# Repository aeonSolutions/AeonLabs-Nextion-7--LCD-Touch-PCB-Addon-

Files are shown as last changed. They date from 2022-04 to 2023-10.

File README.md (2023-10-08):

[PCB-Prototyping-Catalogue](https://github.com/aeonSolutions/PCB-Prototyping-Catalogue)  >>  [Smart LCD Touch Displays](https://github.com/aeonSolutions/PCB-Prototyping-Catalogue/tree/main/Smart%20LCD%20Touch%20Displays)  >>  AeonLabs Nextion 7" LCD Touch PCB Addon

<br>

<p align="right">
    sponsored by <br>
    <a href="https://www.pcbway.com/setinvite.aspx?inviteid=572526">
       
    </a>
</p>

# AeonLabs Nextion 7" LCD Touch PCB Addon 
This repo contains the KiCad files for the  WIFI &amp; BLE addon for Nextion 7" LCD Touch. This PCB adds WiFi and BLE capabilities to stock Nextion 7" LCDs (http://www.nextion.tech). Features WIFI, Bluetooth a RGB LED and a Buzzer and is designed to be mounted on top of existing Nextion PCB board. Optionally:
- can be installed with a RFID RC522 module for contactless read / write capabilities.
- can be installed a barcode & QR code wireless module for handheld barcode & QR code scanners

*Don't forget to LIKE , SHARE and subscribe the free whatsApp group* and if you liked this PCB consider buying me a cup of coffee. Links below.




### Status
  Powers up. Waiting to be tested.

If you already tested this PCB send me a message. Thank you

## Revisions
- revision 3.1
  - added barcode & QR code 2.4G wireless module for handheld barcode & QR code scanners
  - minor bug corrections to the PCB
  
- revision 2.4
  - added wired power source conenction for 5V to 12V 1A power input for industrial applications. 

PCB fabrication of June 2022 (reviision 3.1) was sponsored by [PCBWay](www.pcbway.com)

First Firmware download of AeonLabs's USB to UART TTL Burner (https://www.youtube.com/watch?v=EkAStzBm8CE "First Firmware download of AeonLabs's USB to UART TTL Burner")

## Download options
Download this repository if you need the KiCad Files. or, download the Gerber files in the release section of this repository

## Liked it ? Get a Free PCB for yourself
Send me your Device or hardware and i will design a custom PCB for it. Free of charge. Contact-me on WhatsApp or email for more info. 

## Q&A WhatsApp Group
If you have any Questions or simply  like this kind of projects and want to stay updated with the latest research ideas and prototypes during the day and week, join the WhatsApp Group
[A.I. Things](https://chat.whatsapp.com/FkNC7u83kuy2QRA5sqjBVg)

## Fully assembled PCB
Alternatively, and if you do not want to build a PCB by yourself and like to buy one:

(https://www.tindie.com/stores/aeonlabs/)

The price starts at 30eur plus postage fees.
(I will also deliver the assembled PCB with all the components in place at a fair aditonal cost).

## Nextion LCDs
If you like this , but on another NEXTION LCD TOUCH, drop me a DM on whatsApp [here](https://chat.whatsapp.com/FkNC7u83kuy2QRA5sqjBVg) and i will do for free the KiCad design for you.

#### Be supportive of my dedication and work towards technology education and buy me a coffee. Link below.

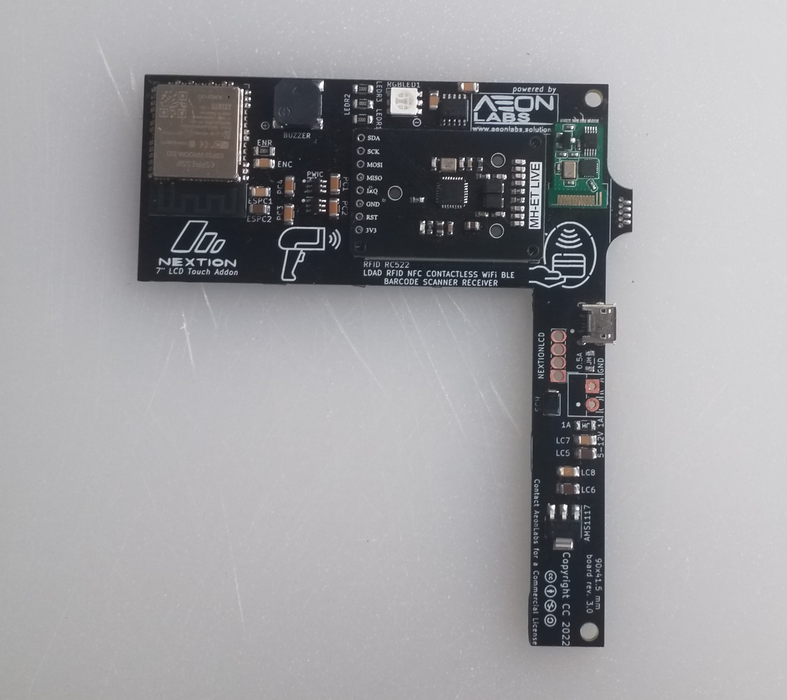
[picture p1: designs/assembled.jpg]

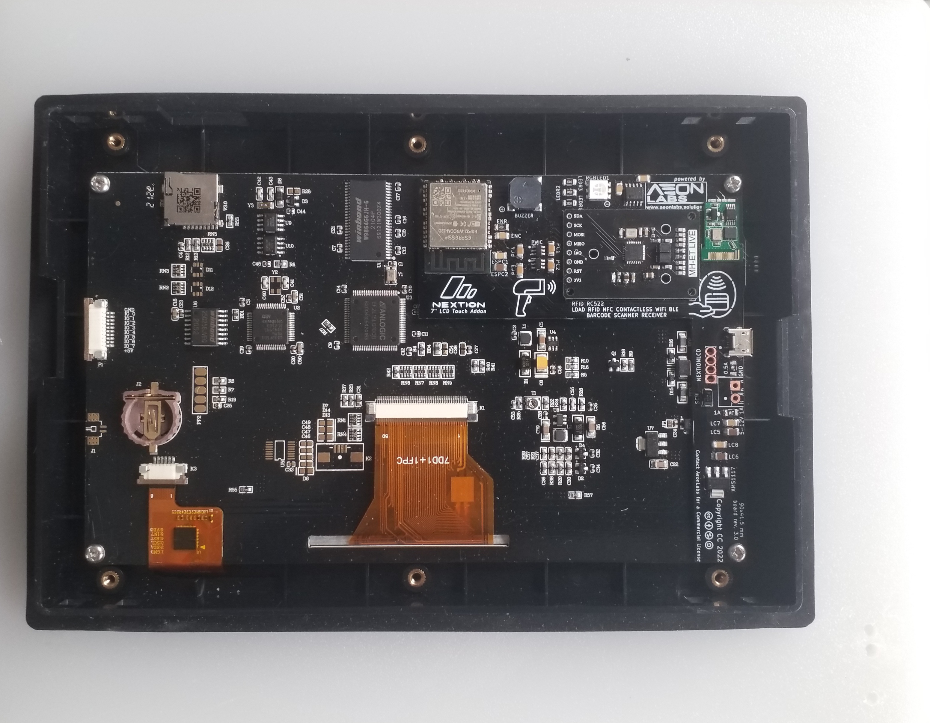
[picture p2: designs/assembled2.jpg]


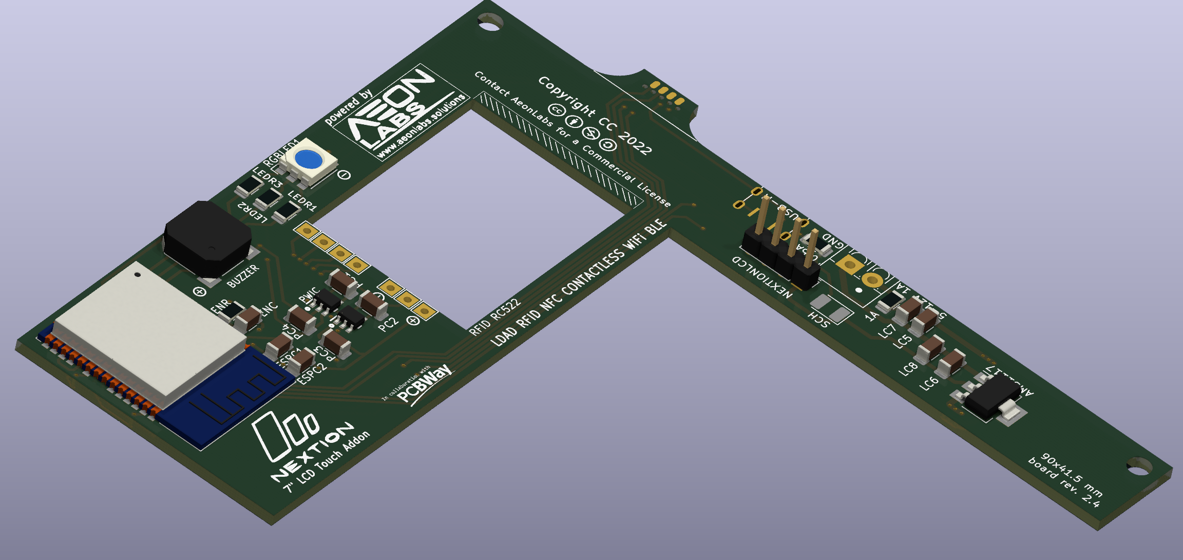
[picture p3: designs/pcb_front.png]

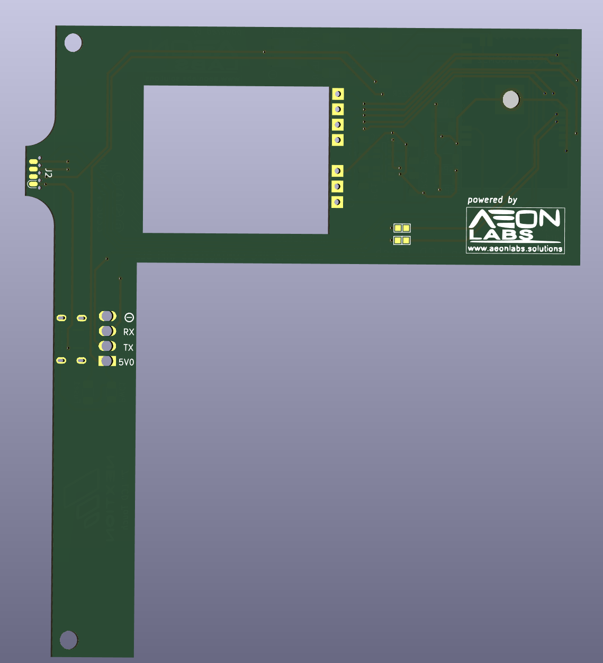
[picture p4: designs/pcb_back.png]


________________________________________________________________________________________________________________

## PCB Parts list
- DC2DC converter HX4002B x2 : https://s.click.aliexpress.com/e/_Ak7IPx
- Capacitor 100nF SMD 1206 : https://s.click.aliexpress.com/e/_AVdmzr
- Capacitor 2.2uF SMD 1206 : https://s.click.aliexpress.com/e/_AVdmzr
- Resistor SMD 1206 330R x3 : https://s.click.aliexpress.com/e/_A7OXrR
- ESP32 WROOM32 x1 : https://s.click.aliexpress.com/e/_AF7N6l
- Buzzer x1: https://s.click.aliexpress.com/e/_AF7N6l
- LED RGB x1: https://s.click.aliexpress.com/e/_AccXHT
- RFID RC522 x1 (optional) : https://s.click.aliexpress.com/e/_Am0LAH
- 

## Firmware Download 
one can use the PCB in the repository [AeonLabs-MCU-Burner-USB-to-UART-TTL](https://github.com/aeonSolutions/AeonLabs-MCU-Burner-USB-to-UART-TTL) to program the ESP32 WROOM32 MCU on this PCB.

<br />
<br />

______________________________________________________________________________________________________________________________

### PCB Conceptualization and Design
<p align="center">
 
[](https://saturnpcb.com) [](https://www.kicad.org) [](https://www.broadcom.com/appcad)

</p>

<br />
<br />

### PCB Fabrication
<p align="center">
 
[](https://www.allpcb.com/?Mb_InviteId=79483) [](https://www.pcbway.com/setinvite.aspx?inviteid=572526) [](https://be.eurocircuits.com)

</p>

<br />
<br />

## Author

You can get in touch with me on my LinkedIn Profile:

#### Miguel Tomas





You can also follow my GitHub Profile to stay updated about my latest projects: 

<br>

### Be supportive of my dedication and work towards technology education and buy me a cup of coffee
The PCB Desgin Files i provide here for anyone to use are free. If you like this Smart Device or use it, please consider buying me a cup of coffee, a slice of pizza or a book to help me study, eat and think new PCB design files.

<p align+"left">
<a href="https://www.buymeacoffee.com/migueltomas">
   
 </a>
<br>

</p>

<br />

### Make a donation on Paypal
Make a donation on paypal and get a TAX refund*.

(http://paypal.me/mtpsilva)

<br>

### Support all these open hardware projects and become a patreon  
Liked any of my PCB KiCad Designs? Help and Support my open work to all by becomming a LDAD Patreon.
In return I will give a free PCB design in KiCad to all patreon supporters. To learn more go to patreon.com. Link below.

(https://www.patreon.com/ldad)

<br />
<br />

______________________________________________________________________________________________________________________________
### License

Before proceeding to download any of AeonLabs software solutions for open-source development and/or PCB hardware electronics development make sure you are choosing the right license for your project. See [AeonLabs Solutions for Open Hardware & Source Development](https://github.com/aeonSolutions/PCB-Prototyping-Catalogue/wiki/AeonLabs-Solutions-for-Open-Hardware-&-Source-Development) for more information. 

______________________________________________________________________________________________________________________________

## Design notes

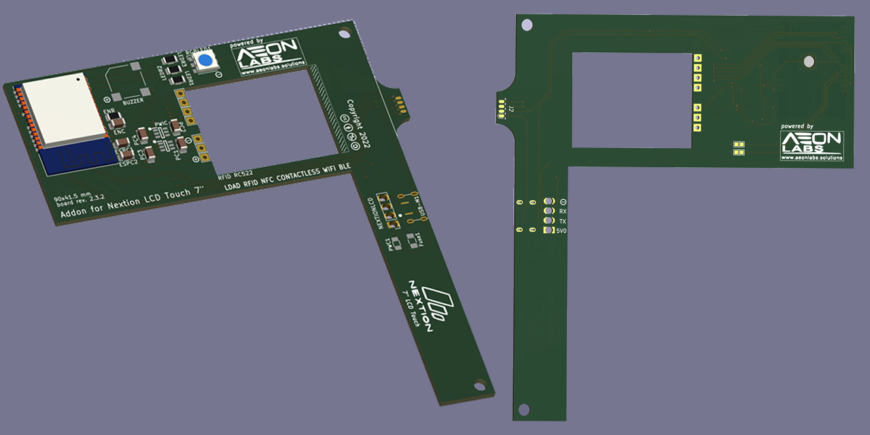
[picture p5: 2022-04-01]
designs/pcb.fw.png

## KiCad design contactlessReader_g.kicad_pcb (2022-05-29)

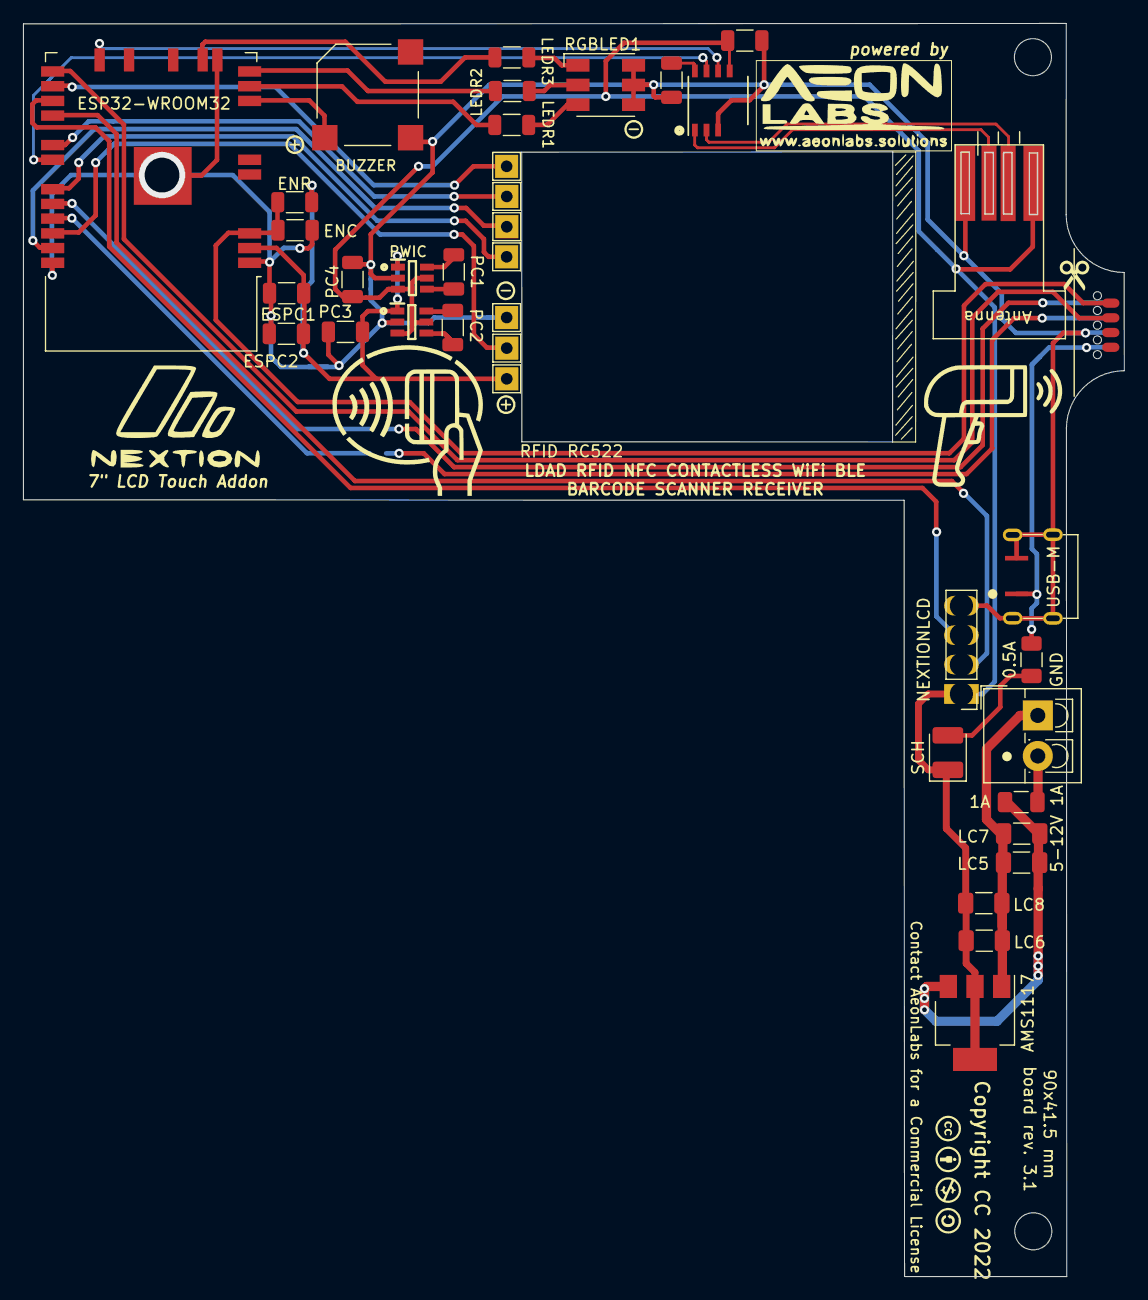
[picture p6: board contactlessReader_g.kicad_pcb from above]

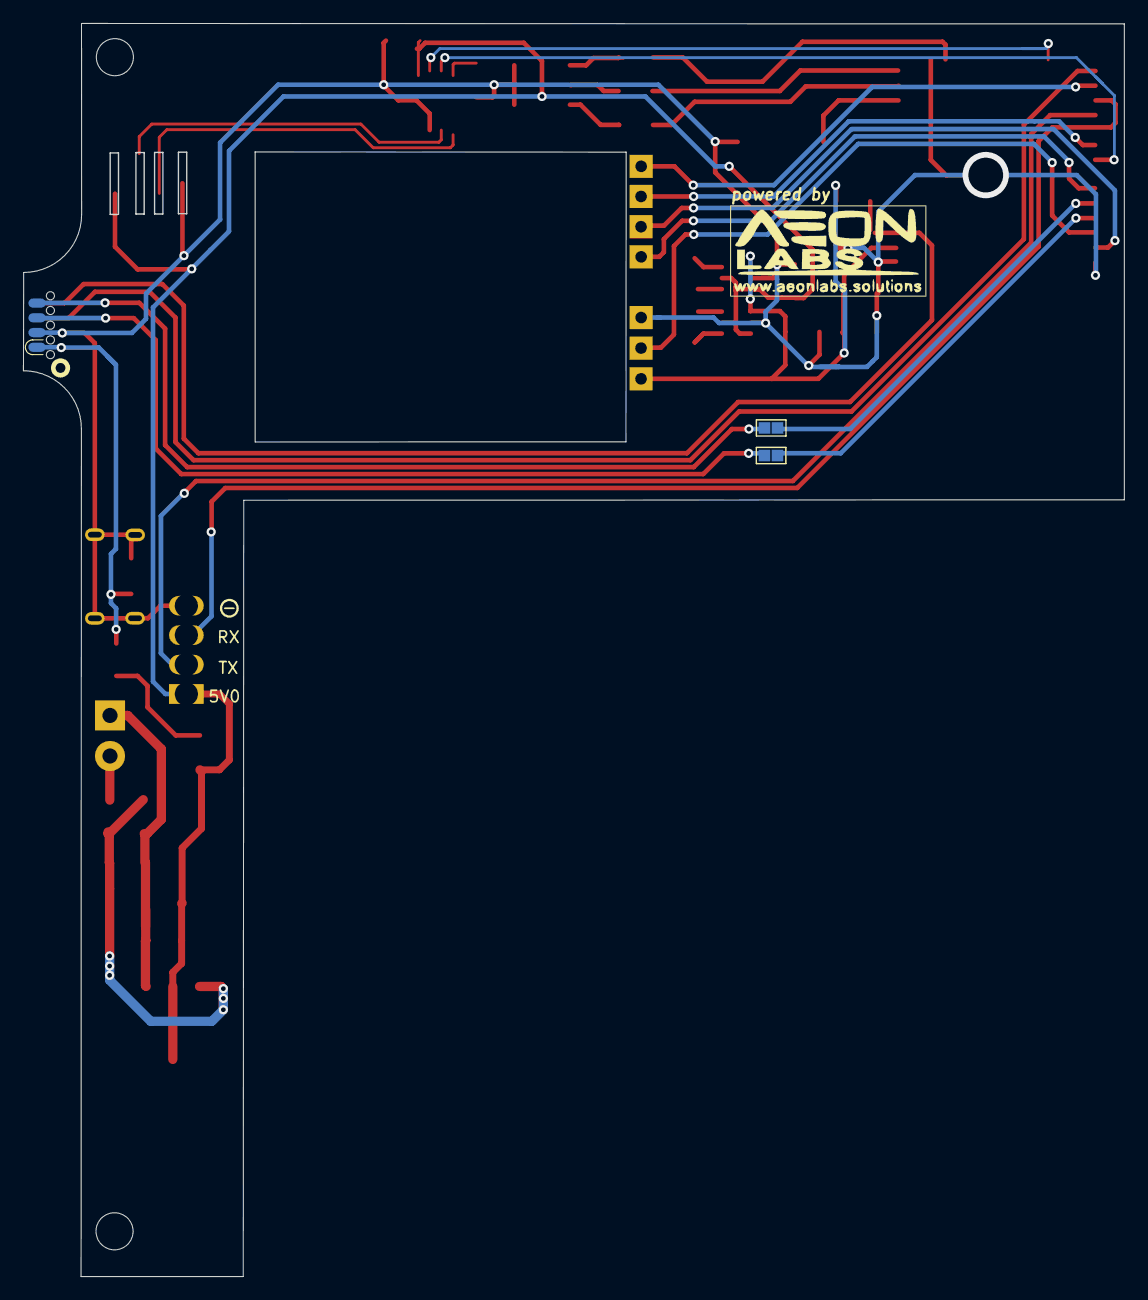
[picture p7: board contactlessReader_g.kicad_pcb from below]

Board: 2 copper layers, 95.0 x 108.1 mm, 43 parts (3 on the bottom side), 37 nets.

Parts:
AMS1117-5.0: AMS1117-5.0; SOT-223-3_TabPin2
BUZZER1: Buzzer; MagneticBuzzer_Kobitone_254-EMB84Q-RO
CH340K1: CH340K1; SSOP-10_3.9x4.9mm_P1.00mm
CHC1, CHC2: 100nF; C_1206_3216Metric
ENR1: 10k; R_1206_3216Metric
ESP32-WROOM32: ESP32-WROOM-32
ESPC1: 0.1uF; C_1206_3216Metric
ESPC2: 22uF; C_1206_3216Metric
ESP_EN_C1: 0.1uF; C_1206_3216Metric
H1, H3: MountingHole; MountingHole_3.2mm_M3_DIN965
HX4002B1: PWIC; HX4002 SOT95 P280X125-6N
HX4002B2: PWIC1; HX4002 SOT95 P280X125-6N
ID3V3: RFID3v3; TestPoint_THTPad_2.0x2.0mm_Drill1.0mm
IDGND1: RFIDGND; TestPoint_THTPad_2.0x2.0mm_Drill1.0mm
IDMISO1: RFIDMISO; TestPoint_THTPad_2.0x2.0mm_Drill1.0mm
IDMOSI1: RFIDMOSI; TestPoint_THTPad_2.0x2.0mm_Drill1.0mm
IDRST1: RFIDRST; TestPoint_THTPad_2.0x2.0mm_Drill1.0mm
IDSCK1: RFIDSCK; TestPoint_THTPad_2.0x2.0mm_Drill1.0mm
IDSDA1: RFIDSDA; TestPoint_THTPad_2.0x2.0mm_Drill1.0mm
J1: Conn_01x04_Male; PinHeader_1x04_P2.54mm_Vertical
J2: Conn_01x08_Male; SOIC_clipProgSmall
J3: Conn_01x04_Male; BarCode Scanner Wireless Receiver PCB Module
LC5, LC6: 22uF; C_1206_3216Metric_Pad1.33x1.80mm_HandSolder
LC7, LC8: 100nF; C_1206_3216Metric_Pad1.33x1.80mm_HandSolder
LEDR1, LEDR2, LEDR3: 330R; R_1206_3216Metric
PC1, PC2, PC3, PC4: 2.2uF; C_1206_3216Metric
PWFUSE1: 1A; Fuse_1206_3216Metric
PWR12V1: PWR12V; TerminalBlock_4Ucon_1x02_P3.50mm_Vertical
RGBLED1: LED_RGB; LED_RGB_5050-6
RX1: RX1; TestPoint_Pad_Bridge_1.0x1.0mm
TX1: TX1; TestPoint_Pad_Bridge_1.0x1.0mm
USB-M1: USB-M; Micro_USB_pcb_socket_5pin_4weld_points
USBFUSE1: 0.5A; Fuse_1206_3216Metric
USB_SCH1: D_Schottky; D_1210_3225Metric_Pad1.42x2.65mm_HandSolder

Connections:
/3V3: ENR1.1, ESP32-WROOM32.2 (VDD), ESPC1.1, ESPC2.1, HX4002B1.1 (VOUT), HX4002B2.1 (VOUT), ID3V3.1, PC3.1
/5V0: AMS1117-5.0.2 (VO), CH340K1.7 (VCC), CHC1.1, HX4002B1.3 (EN), HX4002B1.5 (VIN), HX4002B2.3 (EN), HX4002B2.5 (VIN), J1.1, J3.1, LC6.1, LC8.1, PC4.1, USB_SCH1.1 (K)
/5V0F: J2.1, USB-M1.1 (VBUS), USBFUSE1.2
/GND: BUZZER1.2 (+), CH340K1.3 (GND), CHC1.2, CHC2.2, ESP32-WROOM32.1 (GND), ESP32-WROOM32.15 (GND), ESP32-WROOM32.38 (GND), ESP32-WROOM32.39 (GND), ESPC1.2, ESPC2.2, ESP_EN_C1.1, HX4002B1.2 (GND), HX4002B2.2 (GND), IDGND1.1, J1.4, J2.2, J3.4, PC3.2, PC4.2, RGBLED1.4 (BA), RGBLED1.5 (GA), RGBLED1.6 (RA), USB-M1.5 (GND), USB-M1.6 (Shield)
/IO0_BOOT_DTR: ESP32-WROOM32.25 (IO0), J2.6
/IO01TX: ESP32-WROOM32.35 (TXD0/IO1), RX1.2
/IO03RX: ESP32-WROOM32.34 (RXD0/IO3), TX1.2
/IO04_RF_SDA: ESP32-WROOM32.26 (IO4), IDSDA1.1
/IO12_LED_RED: ESP32-WROOM32.14 (IO12), LEDR2.2
/IO13_LED_GREEN: ESP32-WROOM32.16 (IO13), LEDR3.2
/IO14_LED_BLUE: ESP32-WROOM32.13 (IO14), LEDR1.2
/IO15_U1_RX: CH340K1.8 (TXD), ESP32-WROOM32.23 (IO15)
/IO16_U2RX_NexTX: ESP32-WROOM32.27 (IO16), J1.3
/IO17_U2TX_NexRX: ESP32-WROOM32.28 (IO17), J1.2
/IO18_RF_SCK: ESP32-WROOM32.30 (IO18), IDSCK1.1
/IO19_U1_TX: CH340K1.9 (RXD), ESP32-WROOM32.31 (IO19)
/IO21_RF_MISO: ESP32-WROOM32.33 (IO21), IDMISO1.1
/IO22_RF_RST: ESP32-WROOM32.36 (IO22), IDRST1.1
/IO23_RF_MOSI: ESP32-WROOM32.37 (IO23), IDMOSI1.1
/IO27_BUZZER: BUZZER1.1 (-), ESP32-WROOM32.12 (IO27)
/RST_EN_RTS: ENR1.2, ESP32-WROOM32.3 (EN), ESP_EN_C1.2, J2.5
/RX_IN: J2.3, RX1.1
/TX_IN: J2.4, TX1.1
unnamed: AMS1117-5.0.1 (GND), LC5.1, LC6.2, LC7.1, LC8.2, PWR12V1.1
unnamed: AMS1117-5.0.3 (VI), LC5.2, LC7.2, PWFUSE1.2
unnamed: CH340K1.1 (UD+), J3.3
unnamed: CH340K1.2 (UD-), J3.2
unnamed: CH340K1.10 (V3), CHC2.1
unnamed: HX4002B1.4 (C-), PC1.2
unnamed: HX4002B1.6 (C+), PC1.1
unnamed: HX4002B2.4 (C-), PC2.2
unnamed: HX4002B2.6 (C+), PC2.1
unnamed: LEDR1.1, RGBLED1.3 (BK)
unnamed: LEDR2.1, RGBLED1.2 (GK)
unnamed: LEDR3.1, RGBLED1.1 (RK)
unnamed: PWFUSE1.1, PWR12V1.2
unnamed: USBFUSE1.1, USB_SCH1.2 (A)

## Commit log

2022-04-01 initial commint
    [contactlessReader_licensed.kicad_pcb, contactlessReader_licensed.kicad_sch]
2022-04-23 rev. 2.4
    [contactlessReader_licensed.kicad_pcb, contactlessReader_licensed.kicad_sch]
2022-05-29 revision update
    [contactlessReader_g.kicad_pcb, contactlessReader_licensed.kicad_sch]

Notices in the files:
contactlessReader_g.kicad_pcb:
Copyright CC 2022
